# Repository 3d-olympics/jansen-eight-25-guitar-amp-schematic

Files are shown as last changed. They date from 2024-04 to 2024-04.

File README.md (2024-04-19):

# Jansen Eight 25 guitar amp schematic
### (Classic Aotearoa (NZ) guitar amp brand)


I recently gave this 1960s Jansen guitar amp (classic Aotearoa brand) an internal makeover, and got carried away and mapped out the entire schematic. It’s different to the other Jansen schematics available online. Maybe you’ll find it useful or interesting?

insides

jansen schematic screenshot delete

[View the PDF schematic](Jansen%20Eight%2025%20schematic.pdf) - this contains several more pages showing the sub-blocks.

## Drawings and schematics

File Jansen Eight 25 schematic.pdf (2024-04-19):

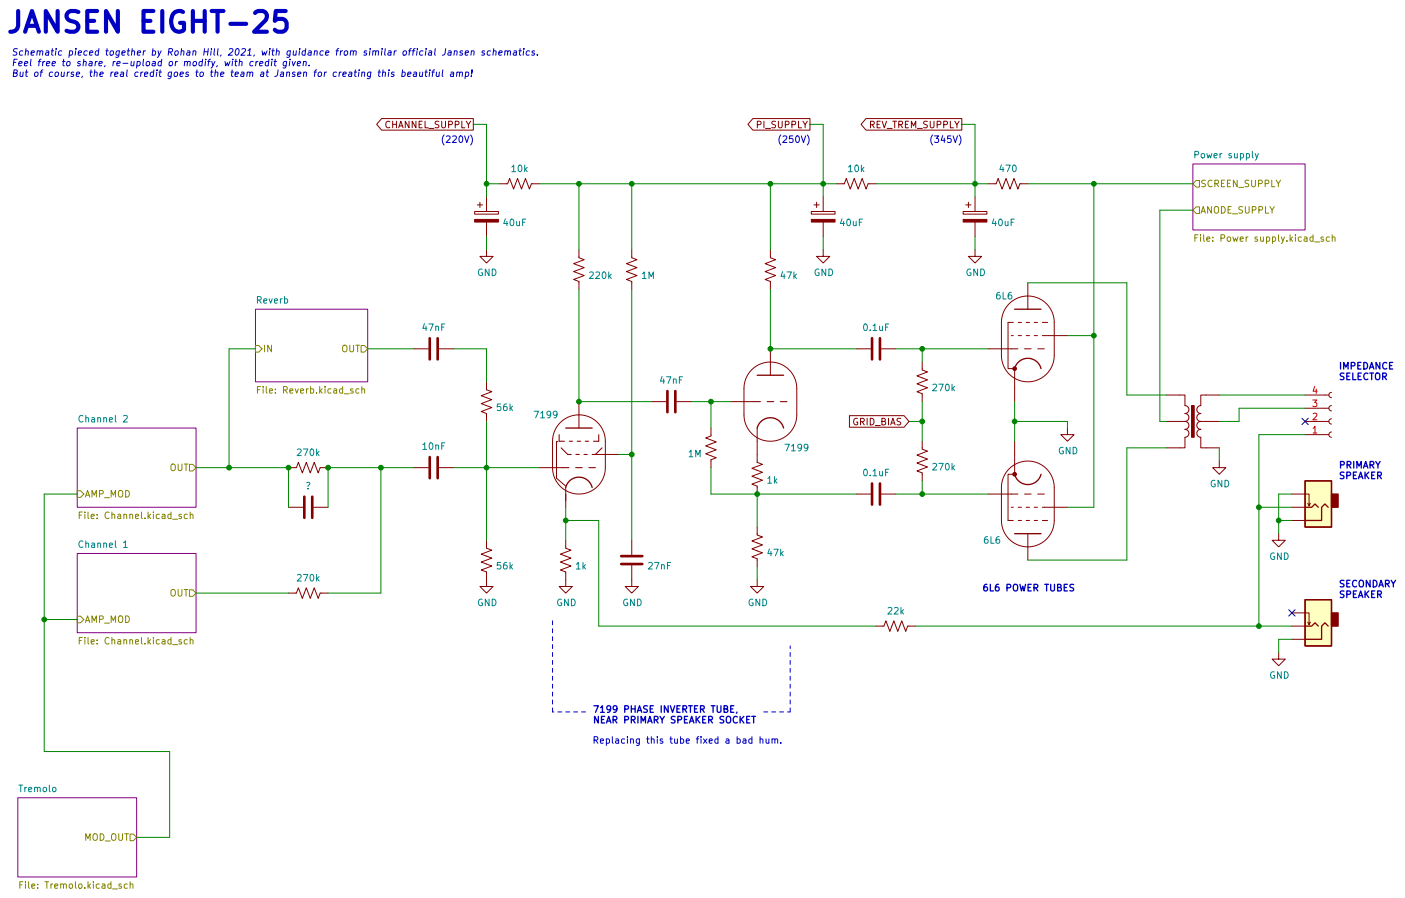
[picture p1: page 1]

Schematic pieced together by Rohan Hill, 2021, with guidance from similar official Jansen schematics.
Feel free to share, re-upload or modify, with credit given.

Channel 2 File: Channel.kicad_sch OUT AMP_MOD

7199 PHASE INVERTER TUBE, NEAR PRIMARY SPEAKER SOCKET Replacing this tube fixed a bad hum.

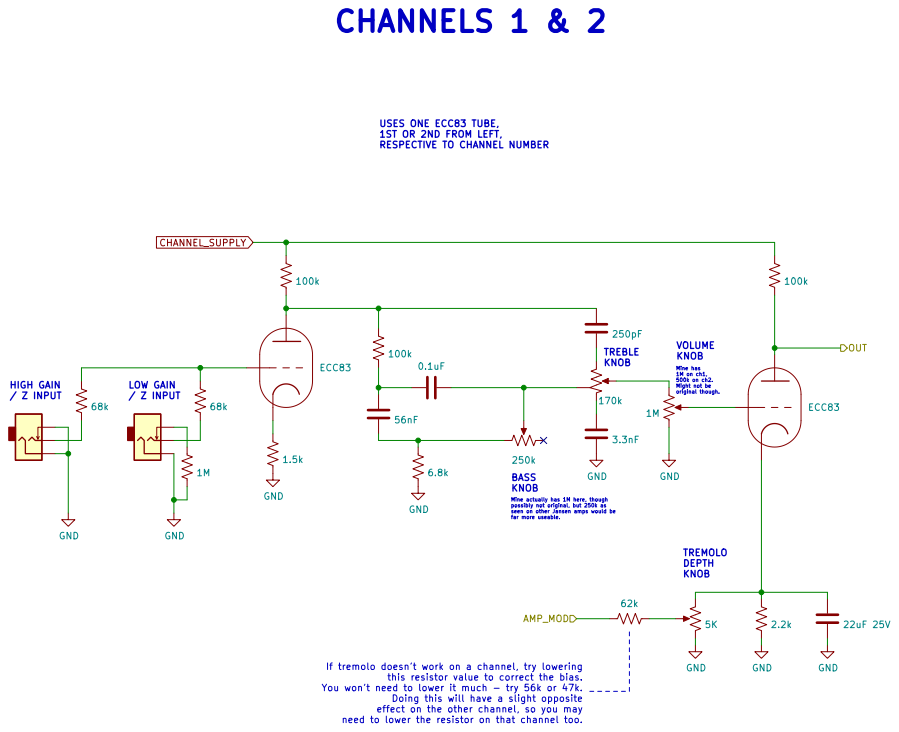
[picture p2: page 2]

1ST OR 2ND FROM LEFT, RESPECTIVE TO CHANNEL NUMBER CHANNELS 1 & 2

original though. USES ONE ECC83 TUBE,
100k GND

Mine has 1M on ch1, 500k on ch2. Might not be

effect on the other channel, so you may need to lower the resistor on that channel too. BASS KNOB

Mine actually has 1M here, though
possibly not original, but 250k as
seen on other Jansen amps would be

far more useable. If tremolo doesn't work on a channel, try lowering

this resistor value to correct the bias. You won't need to lower it much - try 56k or 47k.

Doing this will have a slight opposite

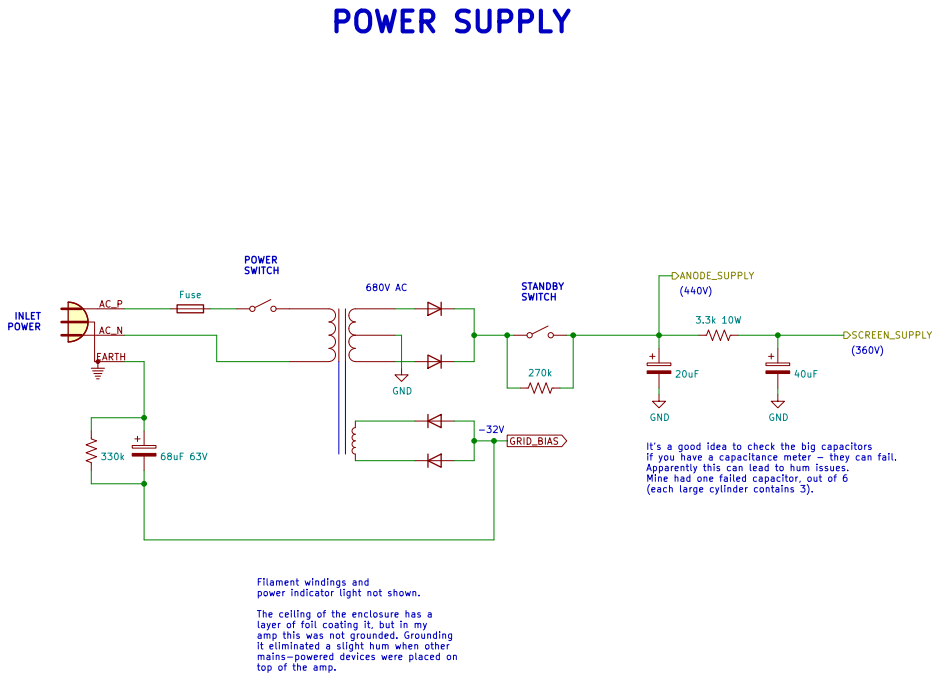
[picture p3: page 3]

It's a good idea to check the big capacitors
if you have a capacitance meter - they can fail.
Apparently this can lead to hum issues.
Mine had one failed capacitor, out of 6
(each large cylinder contains 3).

Filament windings and
power indicator light not shown.

The ceiling of the enclosure has a
layer of foil coating it, but in my
amp this was not grounded. Grounding
it eliminated a slight hum when other
mains-powered devices were placed on
top of the amp.

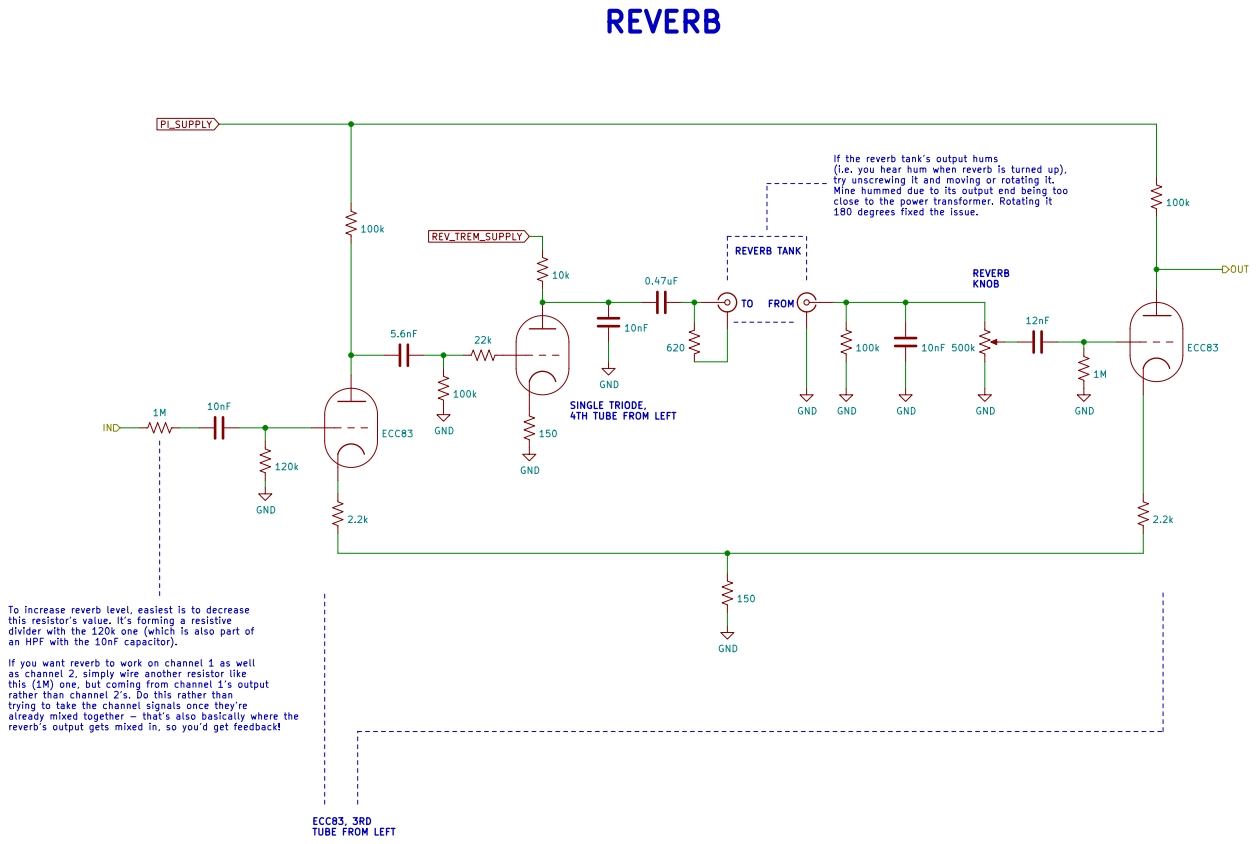
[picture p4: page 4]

SINGLE TRIODE, 4TH TUBE FROM LEFT REVERB

If the reverb tank's output hums
(i.e. you hear hum when reverb is turned up),
try unscrewing it and moving or rotating it.
Mine hummed due to its output end being too
close to the power transformer. Rotating it

180 degrees fixed the issue. REVERB TANK

To increase reverb level, easiest is to decrease
this resistor's value. It's forming a resistive
divider with the 120k one (which is also part of
an HPF with the 10nF capacitor).

If you want reverb to work on channel 1 as well
as channel 2, simply wire another resistor like
this (1M) one, but coming from channel 1's output rather than channel 2's. Do this rather than

trying to take the channel signals once they're
already mixed together - that's also basically where the
reverb's output gets mixed in, so you'd get feedback!

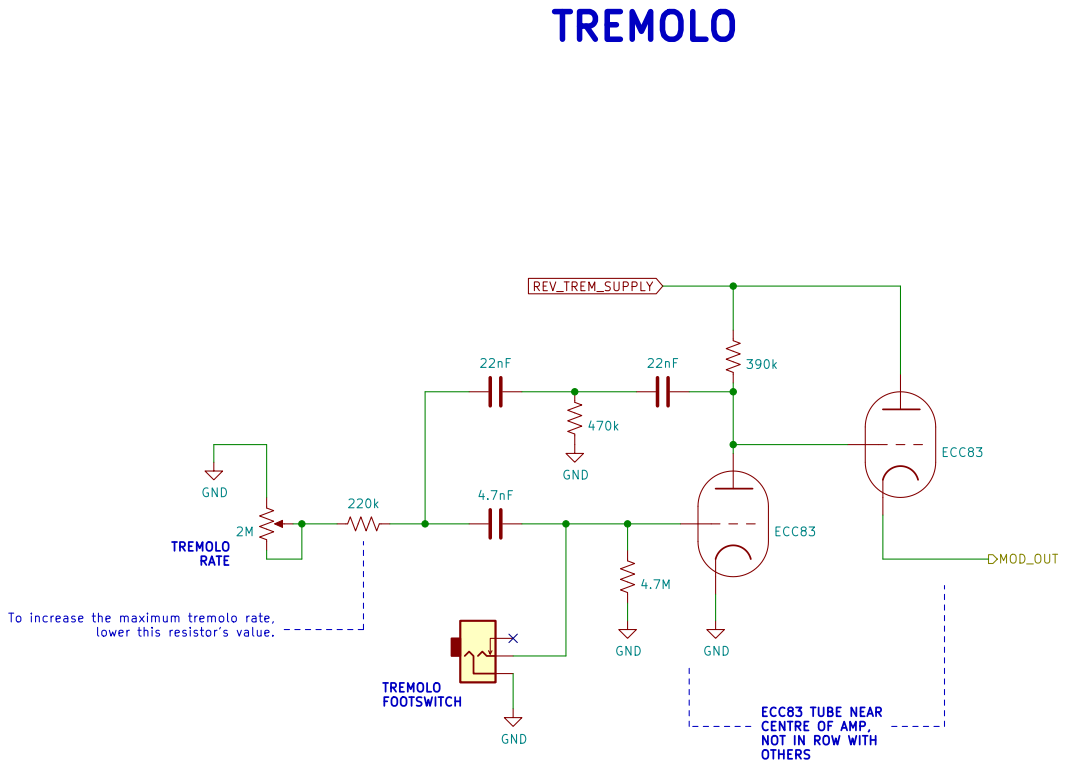
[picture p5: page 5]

To increase the maximum tremolo rate,

ECC83 TUBE NEAR
CENTRE OF AMP, NOT IN ROW WITH OTHERS

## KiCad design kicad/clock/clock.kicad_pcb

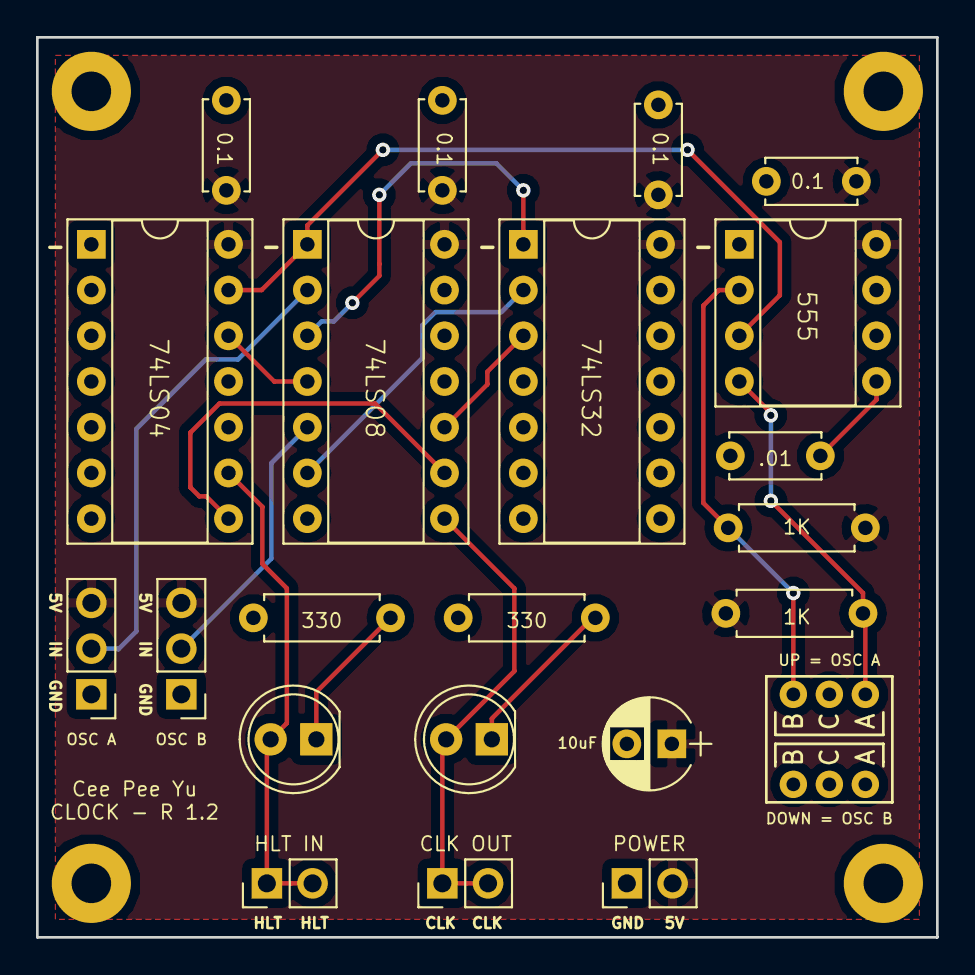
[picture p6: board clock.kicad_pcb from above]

Board: 2 copper layers, 50.0 x 50.0 mm, 22 parts (0 on the bottom side), 17 nets.

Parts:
C1, C2, C3, C6: 0.1uF; C_Disc_D5.0mm_W2.5mm_P5.00mm
C4: 0.01uF; C_Disc_D5.0mm_W2.5mm_P5.00mm
C5: 10uF; CP_Radial_D5.0mm_P2.50mm
D1, D2: LED; LED_D5.0mm
J1: HLT IN; Socket_Strip_Straight_1x02_Pitch2.54mm
J2: CLK OUT; Socket_Strip_Straight_1x02_Pitch2.54mm
J3: 5v IN; Socket_Strip_Straight_1x02_Pitch2.54mm
J4: OSC A; Socket_Strip_Straight_1x03_Pitch2.54mm
J5: OSC B; Socket_Strip_Straight_1x03_Pitch2.54mm
R1, R2: 330; R_Axial_DIN0207_L6.3mm_D2.5mm_P7.62mm_Horizontal
R3, R4: 1K; R_Axial_DIN0207_L6.3mm_D2.5mm_P7.62mm_Horizontal
SW1: SEL SW; SW_DPDT_L7mm_P2mm
U1: 74LS04; DIP-14_W7.62mm_Socket
U2: 74LS08; DIP-14_W7.62mm_Socket
U3: 74LS32; DIP-14_W7.62mm_Socket
U4: LM555; DIP-8_W7.62mm_Socket

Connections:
/HLT: D1.2, J1.1, J1.2, U1.9
/OSC_A: J4.2, U2.2
/OSC_B: J5.2, U2.5
/OUT: D2.2, J2.1, J2.2, U2.8
/SEL: U1.13, U2.1, U4.3
GND: C1.1, C2.1, C3.1, C4.2, C5.2, C6.2, J3.1, J4.1, J5.1, R1.1, R2.2, SW1.2, U1.7, U2.7, U3.7, U4.1, U4.6
unnamed: C4.1, U4.5
unnamed: D1.1, R1.2
unnamed: D2.1, R2.1
unnamed: R3.2, SW1.3, U4.2
unnamed: R4.2, SW1.1, U4.4
unnamed: U1.8, U2.9
unnamed: U1.12, U2.4
unnamed: U2.3, U3.1
unnamed: U2.6, U3.2
unnamed: U2.10, U3.3
VCC: C1.2, C2.2, C3.2, C5.1, C6.1, J3.2, J4.3, J5.3, R3.1, R4.1, U1.14, U2.14, U3.14, U4.8
